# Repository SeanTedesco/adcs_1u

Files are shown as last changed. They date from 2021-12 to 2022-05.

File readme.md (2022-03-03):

# 1.0 Software Setup

Ensure you have python version 3.7 or greater installed on your system, and use this as your default python handle. 

You can determine which python version you are using with the command: 

```
$ python -V
```

And you can determine the location of the python interpreter currently being used with the command:

```
$ which python
```

To change the alias of the python interpreter when running `python` use the following procedure: 

```
$ vim ~/.bashrc
```

Include the line below into the bashrc file (changing the path in qoutes to the one you want):

```
alias python='/c/Users/SeanTedesco/AppData/Local/Programs/Python/Python310/python'
```

Then source the bachrc file to use the changes you just made. 

```
. ~/.bashrc
```

## 1.1 Windows

Please use the following procedure to create your virual environment, activate it, and install all the required packages.

```
python -m venv .venv
source .venv/Scripts/activate
python -m pip install --upgrade pip
pip install -r requirements
```

# 1.2 Mac/Linux

Please use the following procedure to create your virual environment, activate it, and install all the required packages.

```
make clean setup
```

# 2.0 Running the Program

The entry point to the satellite is given in the `main.py` file. Run this to operate the satellite. 

```
python main.py
```

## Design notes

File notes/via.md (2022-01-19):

# VIA INFORMATION

## Via Overview

### What Are Vias? 
Vias are metallic lined holes connected to the metal circuitry of a PCB that conduct an electrical signal between the different layers of the board.

### Why Do We Use Vias?
Using vias in a PCB design allows the designer to shorten the distance that a trace must be routed in order to complete its connection. Just as with the laundry chute, the via will drop the trace down onto another layer where there is a clear path, instead of wandering the long way around. 

## Types of Vias 

**Thru-Hole Via**: This is the type of via that is used most often in a circuit board. The holes are drilled all the way through the board with a mechanical drill bit and can get down to 6 mils in size.

**Buried Via:** This via only connects internal layers of the board and is useful for PCBs with very dense routing.

**Blind Via:** This via starts on either the top or bottom of the board but doesn’t go all the way through it.

## Using Vias In Our Design

**Signal Routing:** Most circuit boards will use a thru-hole via for signal routing placed on a grid. Denser boards, however, may also use blind or buried vias, while very dense boards will need microvias.

**Escape Routing:** Larger surface mount (SMT) components can usually have their escape, or fanout, routing done with thru-hole vias. In some cases, blind vias or microvias will be used. 

**Power Routing:** Since the vias used for power and ground nets will conduct more current, they are usually restricted to larger thru-hole vias, although blind vias may be used as well.

**Stitching Vias:** These vias are used to provide multiple connections to a plane and are, therefore, thru-hole or blind vias. For example, a sensitive area of circuitry may be surrounded by a strip of metal with vias stitched in it to connect to a ground plane for EMI protection.

**Thermal Vias:** In this case, a via is used to conduct heat from a component out through the internal plane layer that it is connected to. This usually requires a larger thru-hole or blind via and these vias are often in the pads of these devices as well.

## Sizing

- There aren’t necessarily any standard PCB via sizes in PCB manufacturing because PCB standard via sizes tend to vary between manufacturers and PCB fabricators. 
- However, there are commonly used drill sizes that many PCB manufacturers prefer to use, and they may refer to them as standard PCB drill sizes. 
- One of the most common sizes is 0.6 mm, but 0.2 mm and 0.3 mm are also commonly used. 

### JCLPCB Capabilities
- **Min. Via Hole Size:** For Single & Double Layer PCB, the minimum via hole size is 0.3mm; For Multi-Layer PCB, the minimum via hole size is 0.2mm.
- **Min. Via Diameter:** For Single & Double Layer PCB, the minimum Via diameter is 0.6mm; For Multi-Layer PCB, the minimum via diameter is 0.4mm.
- **Drill Hole Size:** Supports a minimum of 0.20 mm drill hole size, and a maximum of 6.30 mm dril hole size.

Space School - Level 2 Ideas
- build a 1U cubesat 
- 1-axis reaction wheel
- half duplex communications using nRF24 radios (send and wait for user-acknowledge)
- PCB design and assemply for all components (standardized sizing, via, traces, only to mate with headers and swappable parts)
- Ground Station CLI to control radio
- pi-camera and raspberry pi OBS
- obc

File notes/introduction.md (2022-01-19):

# 1U Mock-Sat 
_Sean Tedesco | 2021-2022 | Queen’s University Student and Xiphos Systems Corporation Intern | Homo Sapien_

# Section 1.0: Introduction 

The Mock Sat is a 1U CubeSat capable of basic telemetry communications; power storage, distribution, and generation, attitude determination; and acquisition of temperature, pressure, and humidity measurements. In order to achieve these technical feats, the Mock Sat include the following subsystems: an electrical power system (EPS) for power storage, distribution, and charging; an attitude determination system (ADS) that produces 9-axis telemetry data; a data acquisition system (PAYLOAD) to collect temperature, pressure, and humidity data; communications system (COMMS) to transmit system health, telemetry and to receive user commands; an on-board computer (OBC) that acts as the central connection between the subsystems mentioned hitherto; a mechanical system (MECH) that encompasses the chassis housing all other subsystems. 

The Mock Sat is an education tool for the Queen’s Space Engineering Team in order to demonstrate a basic working implementation of each of the mentioned satellite subsystems. As such, it is beneficial to outline some learning objectives prior to any undertaking in order to align priorities. These learning objectives are described proceedingly. 

## 1.1 Simple PCB Design 
PCB designs shall be created using open source tools such as KiCad. 

## 1.2 OSI Network Model 
The 7-layer OSI model provides some pointers for code implementation. This is meant to be used as guiding principles to implement layers of abstraction for the microcontrollers as well as some of the sensors and devices, such as the COMMS radios, found on the cubesat. This is expanded on in Software Considerations. 

## 1.3 Advanced Hardware Features
 DMA, Interrupts, Resets, Watch Dogs are to be included in the scope of the cubesat project. 

## 1.4 Software Architecture 
(system managers, task routines)

First and foremost, decisions for this project are guided by the question: “Will this allow me to achieve the goal of an operating 1U cubesat the most efficiently?” 

#Hardware Considerations

Each subsystem is reduced in scope from a satellite that could be launched to space. This reduction in scope is made to reduce the time it takes to build this project, as well as reduce the cost of this project. This is to say that this 1U CubeSat will not be composed of flight hardware; assembled using cheap commercial, off-the-shelf (COTS) components. A complete BOM can be found in Appendix A - BOM. 

Some general considerations for hardware and mechanical design from a systems perspective include:
Have all areas of the cubesat that interact with the operator be located at the outside edges where at all possible. This includes LED indicator lights, charging ports, sd card slots, debugging ports. The motivation behind this is to eliminate the need to adjust and/or move the internal components of the cubesat. This prevents wear and tear, as well as some possible damage from 
The MECH subsystem has been typically left last in consideration in designing a cubesat on QSAT. This has resulted in over cramped designs, frustrations about fixing band aid solutions, providing a barrier to work on it intuitively, and performing the same adjustments over again. To mitigate this each of the subsystems in the cubesat will have a dedicated hardware section when the design is being undertaken. 
Software Considerations
The software architecture for this 1U cubesat is modelled after the 7-layer [OSI Network Model](https://en.wikipedia.org/wiki/OSI_model). The motivation for this is to provide layers of abstraction between the operator of the satellite and the individual hardware components, be able to have more than one person working on it at a time (people should be able to work on one layer without having to consider the layers above them), and have the software be contributed to with an aligned vision. I have interpreted and mapped the OSI model as a way to organize and structure the software, which is outlined below.  

| OSI MODEL LAYER | RELATION TO SOFTWARE ARCHITECTURE |
|PHY	| Have a controller be able to read / write to itself. |
|DATA	| Have a controller be able to read / write to other controllers. |
|NET  	| Have a controller be able to read / write to other controllers. |
|TRAN 	| Error checking, polling, request to send, clear to send. |
|SESS	| Implement a controller as a state machine. |
|PRES	| Format I/O data (from/to sensors, reaction wheels, camera, operator, ground station). |
|APP	| Receive / display raw I/O data (from/to sensors, reaction wheels, camera, operator, ground station).  |

Communications: Hardware
The objective of the communications (COMMS) system is, at the highest level, the ability to talk to the mock-sat from a distance. We are not going to quantitatively define the distance at which is sufficient for a successful design for the COMMS system. Since this project does not emphasize a scientific payload, thus mission performance does not drive design. We are concerned with getting something working. As such we are going to adopt a version of the [SWaP-C  strategy](https://www.baesystems.com/en-us/definition/what-is-swap-c#:~:text=SWaP%2DC%20is%20an%20acronym,device%2C%20system%2C%20or%20program.). Which is concerned with optimizing the size, weight, power, and cost of a system. With this strategy in mind, the requirements, and their corresponding justifications are given below. 

| # | Requirement		| Justification |
| 1 | Low Power 		| Power is limited for the entire satellite.  |
| 2 | Minimal Components 	| Reduces cost and complexity of the system.  |
| 3 | Minimal Volume 		| Space is limited for the entire satellite. |
| 4 | Minimal Cost 		| Project is more accessible if cheaper. |
| 5 | Swappable Components 	| Components break. |
| 6 | Visible System Status 	| Useful for debugging when no access to a serial monitor. |

The components used for the COMMS system include the following: 

| # | Component Name 	| Component Description | 
| 1 | Arduino Nano		| COMMS system controller |
| 2 | nRF24 Radio		| Implements wireless data transmissions |
| 3 | Capacitor 			| Required for nRF24 radio to regulate voltages |
Communications: Software
Requirements
Minimal manipulation of bytes between operator and satellite control logic. 
Does not interrupt operations of any other subsystem when performing system operations. 
Satellite communication remains reliable independent of the failure of other subsystems.
Handles commands from operator to satellite, 
Handles confirmations and data transfers from satellite to operator.

Steps 
RF24 Getting Started Example 
Groundstation and Satellite Code Split
Integrate Battery and Physical Indicators 
Mechanical
ADCS
Weighted rod for pointing? Saw this somewhere for a minimalist approach to ADCS. 
Python ADCS visualization
Figure out what quaternions are
Can you change orbit with an ADCS? If you change your center of gravity can that adjust your orbit? How does a satellite change its orbit? How does a satellite enter and stay into its orbit? 

MPU-650 -toast sat example code (lab4) has a Processing visualizer (check that out) 

For a build reference: 
https://charleslabs.fr/en/project-Reaction+Wheel+Attitude+Control 
https://github.com/CGrassin/reaction_wheel

Determine MOI for satellite: maybe use solid edge? 
On-Board Computer 
Electrical Power System 
Payload
Lab Overview 

Lab 1 - Communication Hardware
Lab 2 - Communication Software
Talk to something at a distance. 
Lab 3 - Power Hardware
Lab 4 - Power Software
Talk to something at a distance that is not tethered to anything. 
Lab 5 - OBC Hardware
Lab 6 - OBC Software
Talk to something at a distance that is not tethered to anything and does something simple. 
Lab 7 - Payload Hardware 
Lab 8 - Payload Software 
Talk to something at a distance that is not tethered to anything and does something cool. 
Lab 9 - Chassis Hardware 
Talk to something at a distance that is not tethered to anything and does something cool and can be easily held. 
Lab 10 - ADCS Hardware
Lab 11 - ADCS Software 
Talk to something at a distance that is not tethered to anything, does something cool, can be easily held, and can adjust its axis in 1 dimension. 

Nominal Layout 
Top - Reaction Wheel, Arduino Nano, MPU6050, Logic Shifter, Motor Driver 
Bottom - Arduino Nano, Radio, Antenna 
Front - Sensors 
Back - Raspberry PI
Left - Batteries, Arduino Nano, Charger, Booster 
Right - Cables and routing. 

Ideas
Mock-Sat Constellation 
Orbit Changing Satellite 
Appendix A - BOM

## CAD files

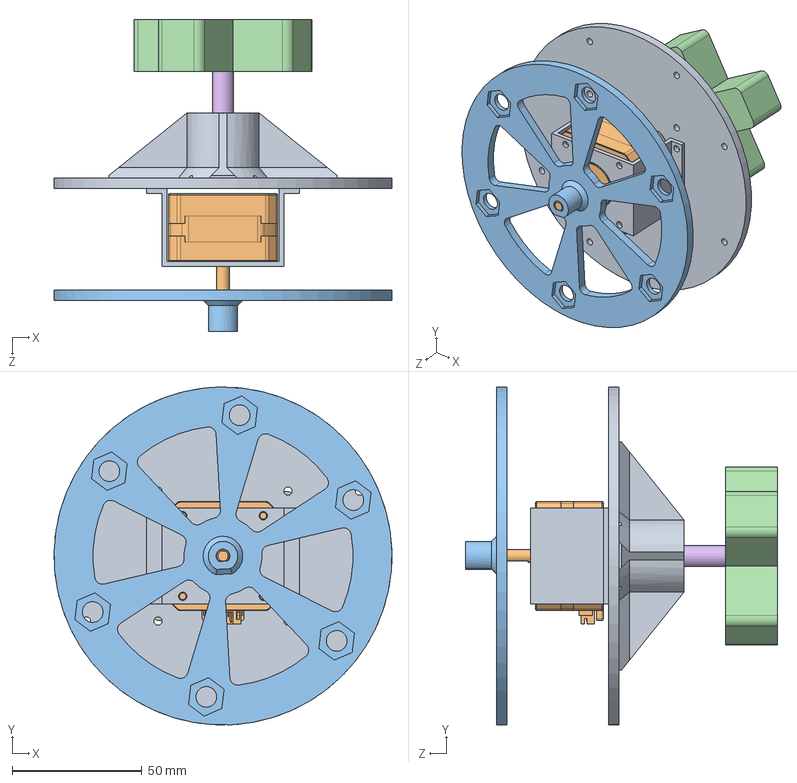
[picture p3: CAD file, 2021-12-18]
hardware-files/solid_edge_src/Assembly/RW_Assembly.SLDASM
130.0 x 130.0 x 120.0 mm
RW_Satellite
E3D Slimline Stepper Motor 0.9deg V1.1
RW_Flywheel
RW_Base
8mm Bearing SKF 608 (RS 286-7530) x 2
8mm_threaded_rod

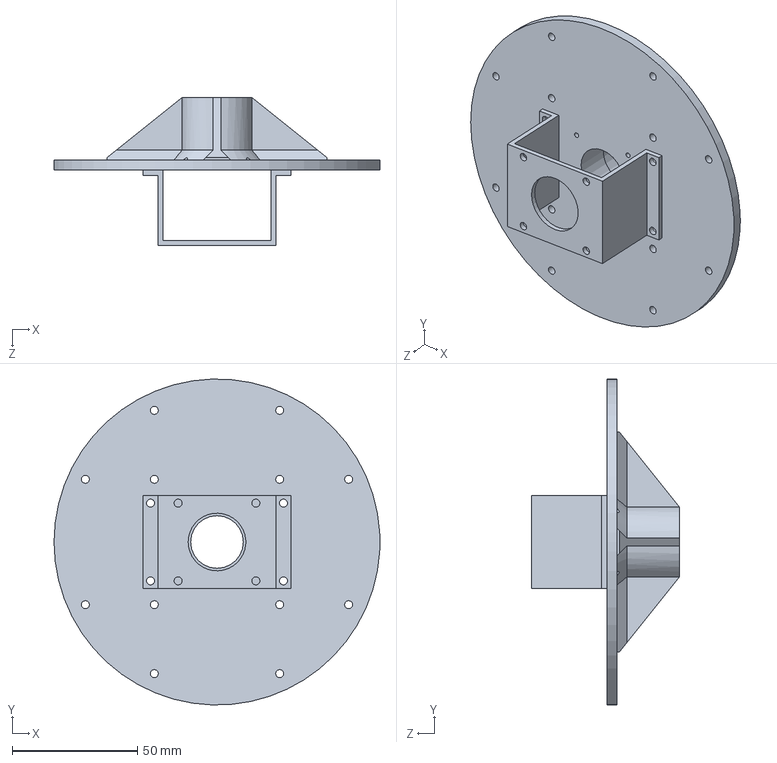
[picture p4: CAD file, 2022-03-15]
hardware-files/solid_edge_src/RW_Satellite.SLDPRT
130.0 x 129.9 x 59.0 mm

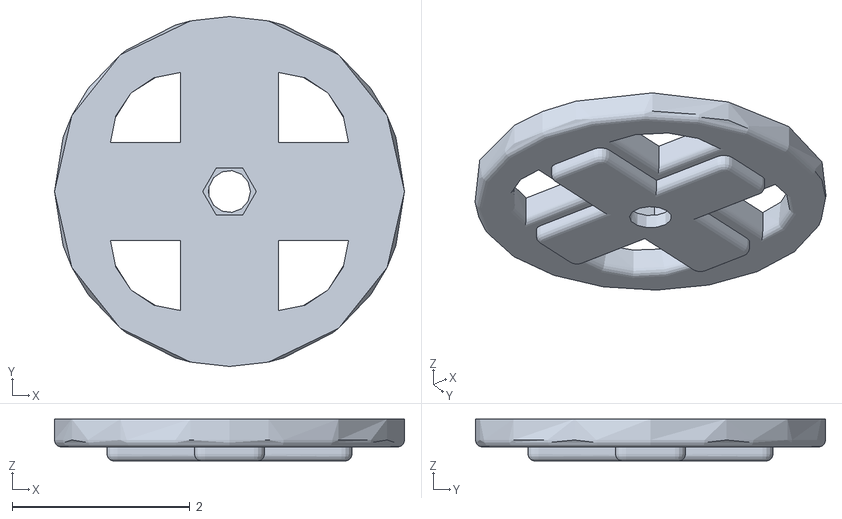
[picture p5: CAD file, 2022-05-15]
hardware-files/stl_files/base_unit_stand.stl
3.94 x 3.94 x 0.472

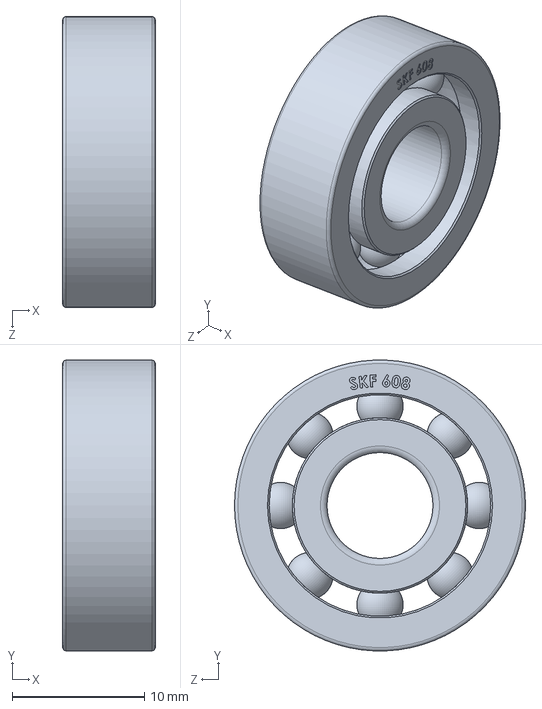
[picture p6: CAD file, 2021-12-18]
hardware-files/solid_edge_src/Assembly/8mm Bearing SKF 608 (RS 286-7530).SLDPRT
7.00 x 22.0 x 22.0 mm

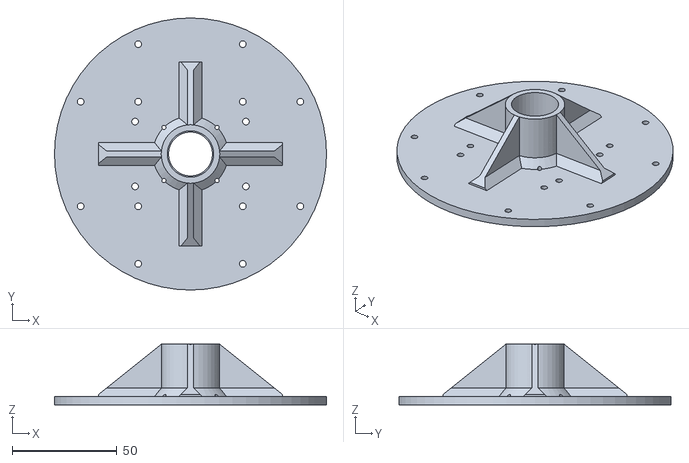
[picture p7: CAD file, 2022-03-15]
hardware-files/stl_files/base_unit_flat.STL
130.0 x 130.0 x 29.0

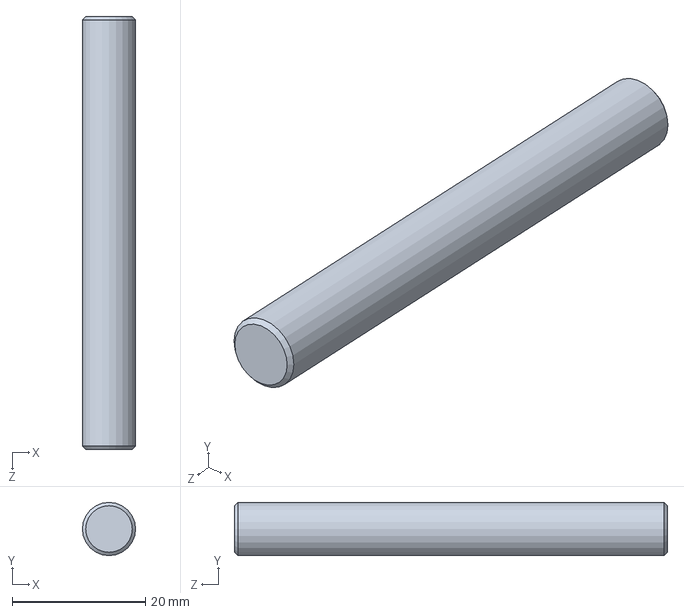
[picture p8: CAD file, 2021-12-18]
hardware-files/solid_edge_src/Assembly/8mm_threaded_rod.SLDPRT
8.00 x 8.00 x 65.0 mm

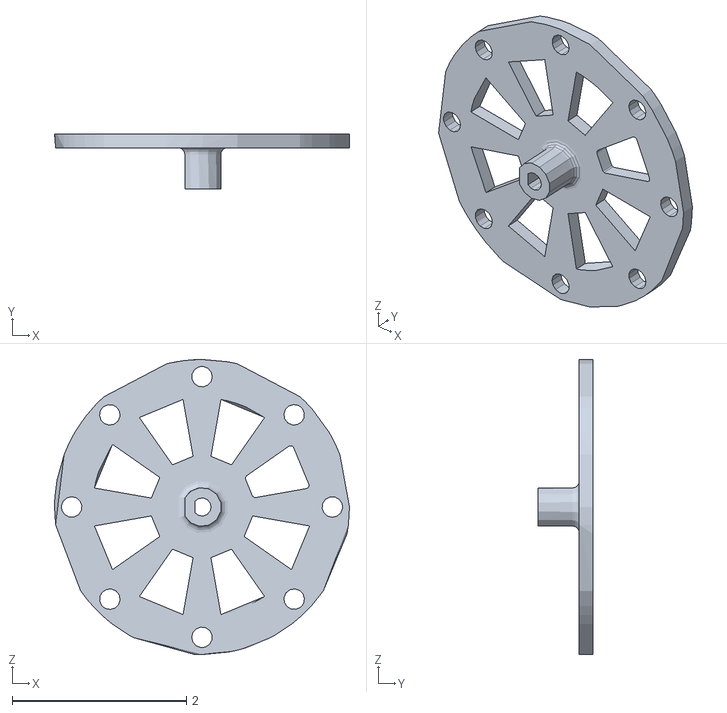
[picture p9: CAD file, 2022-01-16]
hardware-files/stl_files/flywheel_small.stl
3.39 x 0.63 x 3.39

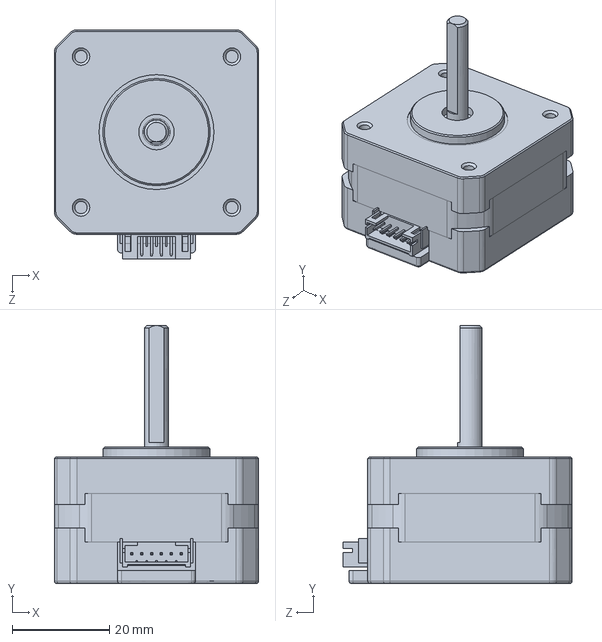
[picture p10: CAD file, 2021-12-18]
hardware-files/solid_edge_src/Assembly/E3D Slimline Stepper Motor 0.9deg V1.1.SLDPRT
42.0 x 53.0 x 47.1 mm

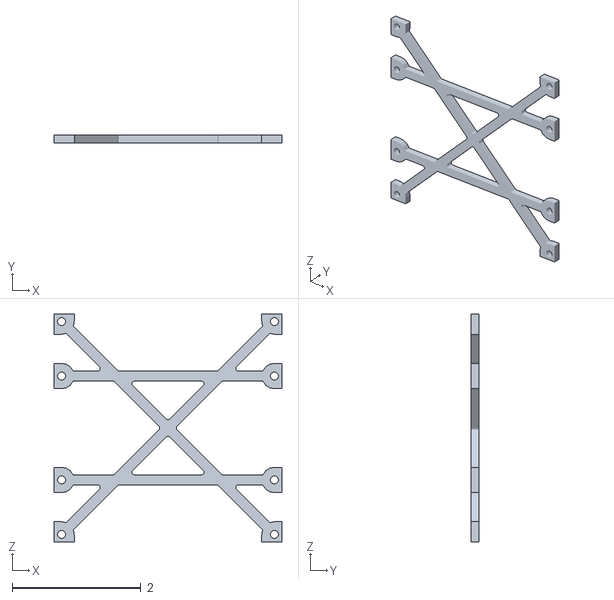
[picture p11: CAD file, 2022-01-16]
hardware-files/stl_files/base_unit_wall.stl
3.54 x 0.118 x 3.54

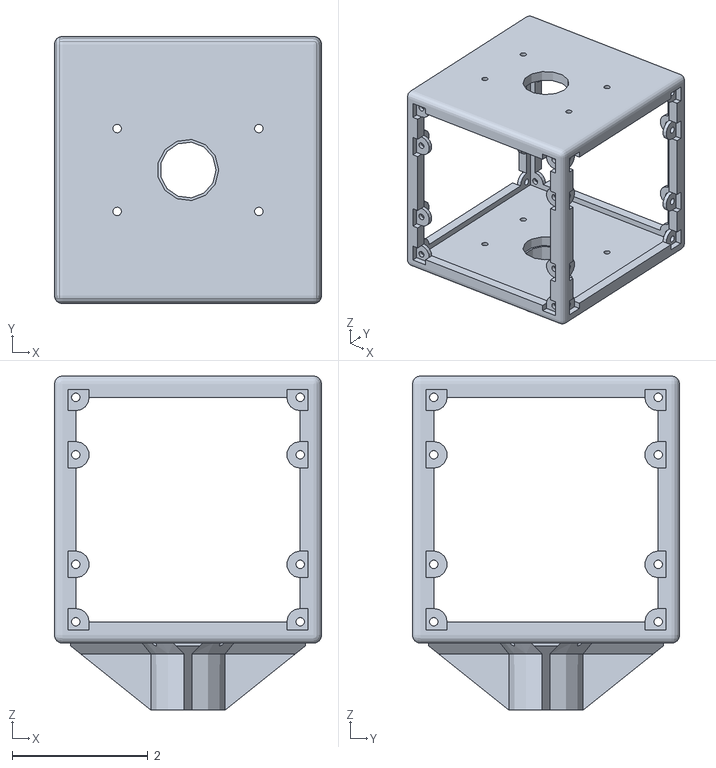
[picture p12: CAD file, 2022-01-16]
hardware-files/stl_files/base_unit_extra_support.stl
3.94 x 3.94 x 4.92

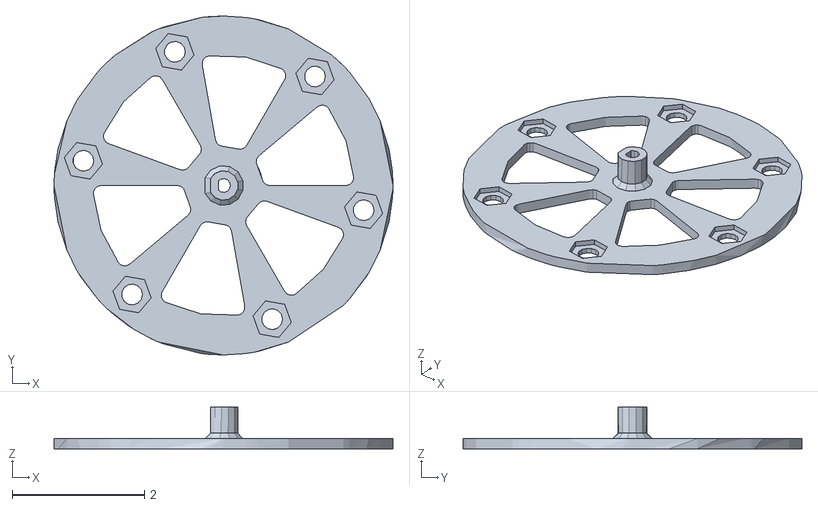
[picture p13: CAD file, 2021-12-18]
hardware-files/stl_files/flywheel_large.stl
5.12 x 5.12 x 0.63

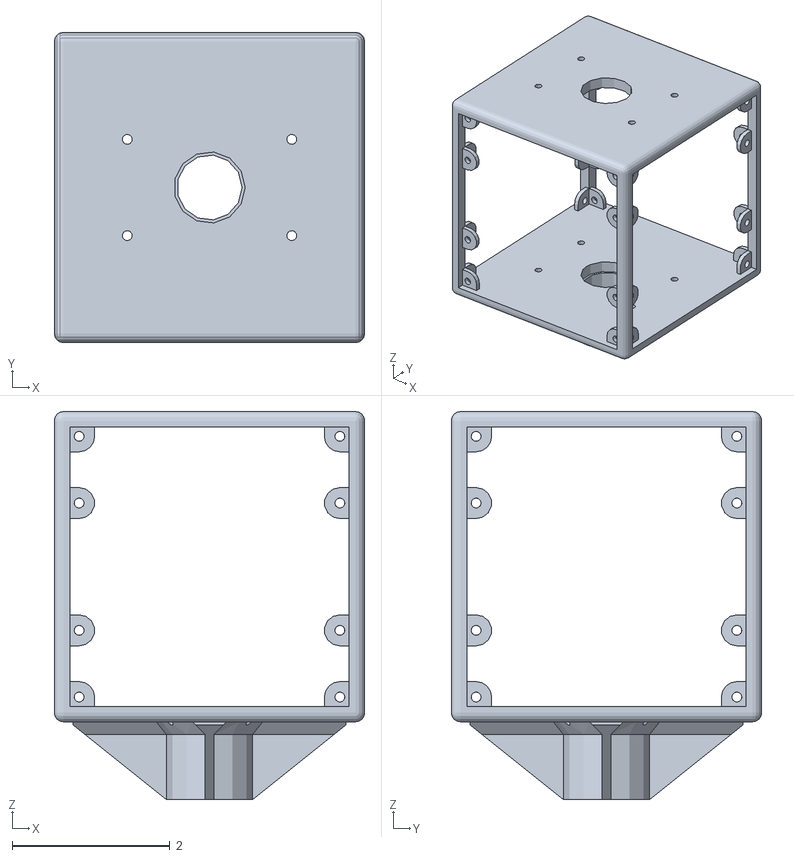
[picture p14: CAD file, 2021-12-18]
hardware-files/stl_files/base_cube_unit.stl
3.94 x 3.94 x 4.92

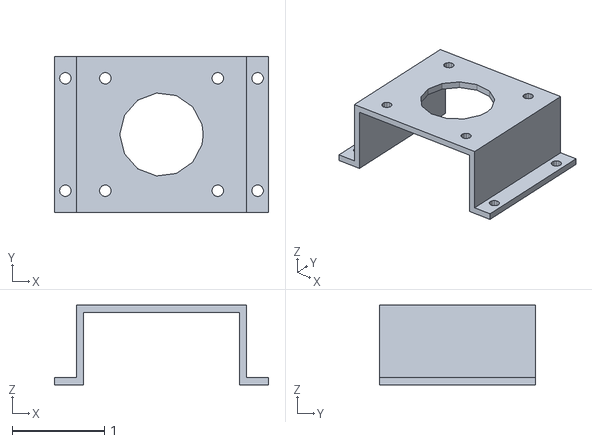
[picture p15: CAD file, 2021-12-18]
hardware-files/stl_files/motor_mounting_bracket.stl
2.32 x 1.69 x 0.866

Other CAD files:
hardware-files/solid_edge_src/RW_Assembly.STEP

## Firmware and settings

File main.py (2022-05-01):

#####################################
# IMPORTS
#####################################
from satsystems.radio.rf24 import RF24
from satsystems.gps.grove import Grove
from satsystems.camera.picam import PiCam
from satsystems.logger.logger import SatelliteLogger
from gpiozero import LED
from time import sleep

class OBC:
    def __init__(self):
        self.logger = SatelliteLogger.get_logger('main.py')
        self.green_led = LED(22)
        self.yellow_led = LED(23)
        self.red_led = LED(24)

        self.expected_commands = [
            'smile',
            'picture',
            'rotate',
        ]

    def run_command(self, cmd, *args, **kwargs):
        cmd = cmd.strip()
        if cmd is None:
            raise ValueError('no command given to obc!')
        
        if cmd == 'smile':
            self.do_smile(*args, **kwargs)
            return True
        
        if cmd == 'picture':
            self.do_picture(*args, **kwargs)
            return True

        if cmd == 'rotate':
            self.do_rotate(*args, **kwargs)
            return True

    def do_smile(self, *args, **kwargs):
        for i in range(5):
            self.red_led.on()
            sleep(1)
            self.red_led.off()
            sleep(1)

    def do_picture(self, *args, **kwargs):
        pass

    def do_rotate(self, *args, **kwargs):
        pass


def main():

    '''initialize all the systems'''
    obc = OBC()
    obc.logger.info('begining main satellite program')

    comms = RF24(port='/dev/ttyACM0')
    obc.logger.info('created comms')

    grove_gps = Grove(uid='gps-2', port='/dev/ttyUSB1', baudrate=115200)
    obc.logger.info('created gps')

    payload = PiCam()
    obc.logger.info('created payload')


    '''main loop'''
    while True:
        msg_received = comms._receive_single_message()
        if msg_received in obc.expected_commands:
            obc.logger.info(f'starting command: {msg_received}')
            try:
                obc.run_command(msg_received)
                obc.logger.info(f'finished command: {msg_received}')
            except:
                obc.logger.warning(f'failed to run command: {msg_received}')
        sleep(1)
        obc.yellow_led.toggle()

if __name__ == '__main__':
    main()

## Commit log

2022-01-16 cad: extra support for base unit, small flywheel
2022-01-16 cad: include updated stl files
    [base_unit_extra_support.stl, base_unit_wall.stl, flywheel_large.stl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]
2022-02-07 lib: radio: start to include some radio params
    each radio will essentially be a serial device that can be quered
    and have its state updated.
2022-02-08 all: understand local imports vs packages
    thinking about switching structure to two repos, first
    for space-systems, and second for satellite-main with tasks
    pros: very clean structure, can debug individual systems,
    each system gets dedicated support without affecting each
    other, regardless of path
    cons: code is everywhere, a bit less on-demand debugging
2022-02-17 all: reorganize directory structure
    [8mm Bearing SKF 608 (RS 286-7530).SLDPRT, 8mm_threaded_rod.SLDPRT, E3D Slimline Stepper Motor 0.9deg V1.1.SLDPRT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]
2022-03-15 hardware: rw: add flat unit for easier printing
    [RW_Satellite.SLDPRT, base_unit_flat.STL]
2022-05-15 reaction wheel: move to satellite-systems repo
2022-05-15 hardware: bigger base unit stand
    [base_unit_stand.stl]
